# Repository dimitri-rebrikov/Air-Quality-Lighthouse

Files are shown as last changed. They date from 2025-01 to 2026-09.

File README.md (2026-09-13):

# Air-Quality-Lighthouse
Implementation of an indoor air quality monitor based on [ESPhome](https://esphome.io/) and built inside of a lighthouse model.

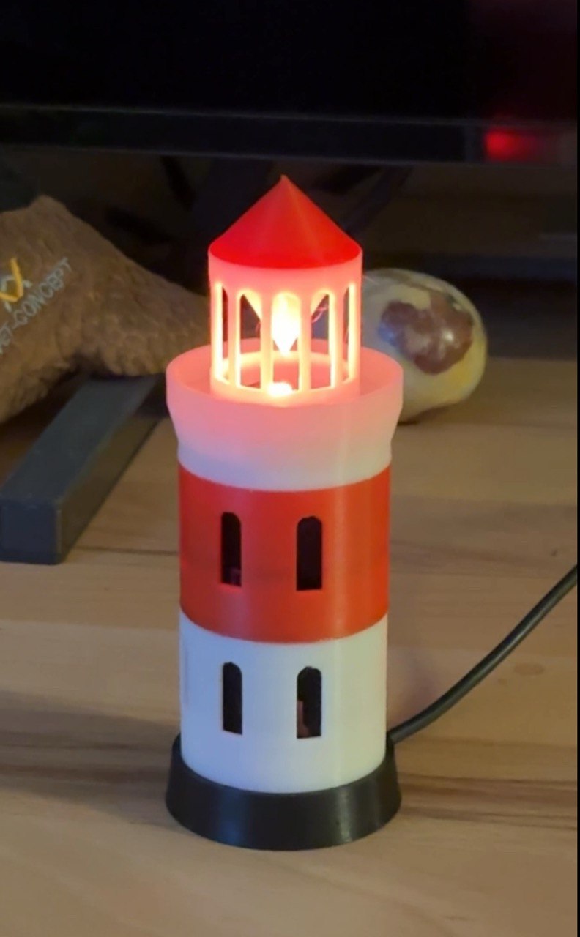
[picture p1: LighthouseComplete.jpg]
Lighthouse Complete


## Summary

The idea came from https://www.thingiverse.com/thing:5652921 where the ESP module's heat creates a chimney effect inside of the lighthouse model ensuring the air quality sensor always gets the air from outside of the housing.

This project provides the similar functionality: 
- visualizing of the air quality over the RGB LED light in the traffic light manner: from green over yellow to the flashing red 
- sending of the detailed air and environmental information to the home automation server

Instead of the direct coding in C/C++ it uses the ESPhome environment and "just sticks" the parts already implemented there together.

The lighthouse model is designed in OpenSCAD and is parametrizable so that it possible to use different ESP, Air Sensor and LED modules.

### Gallery

| | | |
| --- | --- | --- |
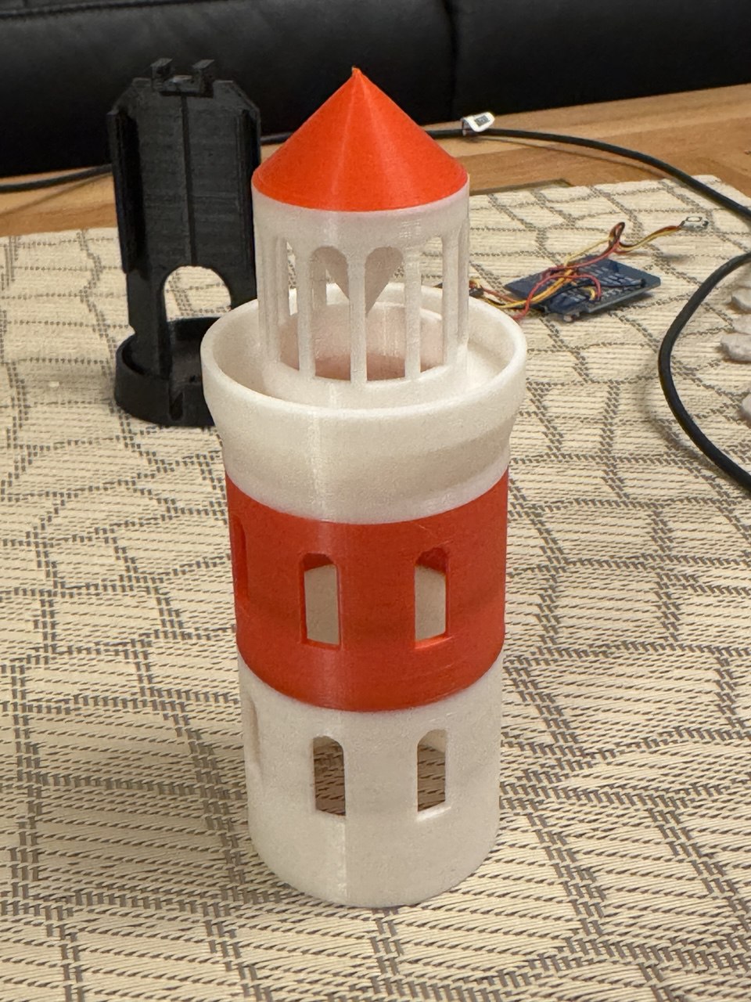
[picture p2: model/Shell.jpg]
Shell
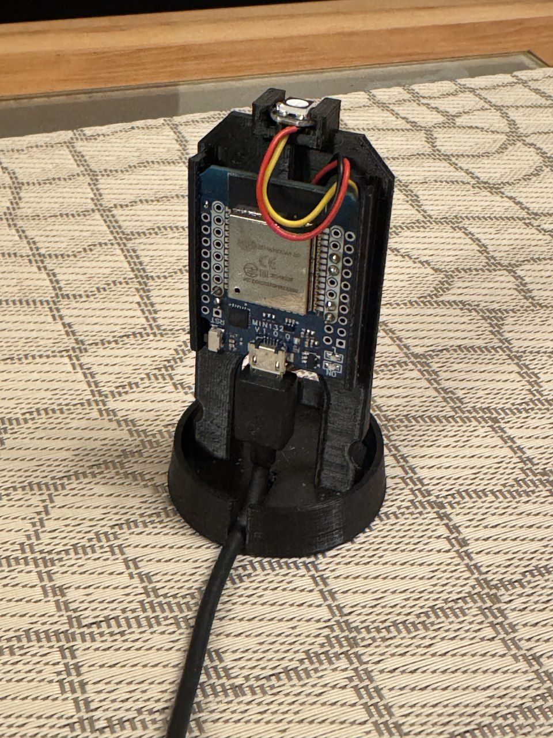
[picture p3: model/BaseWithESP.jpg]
BaseWithESP
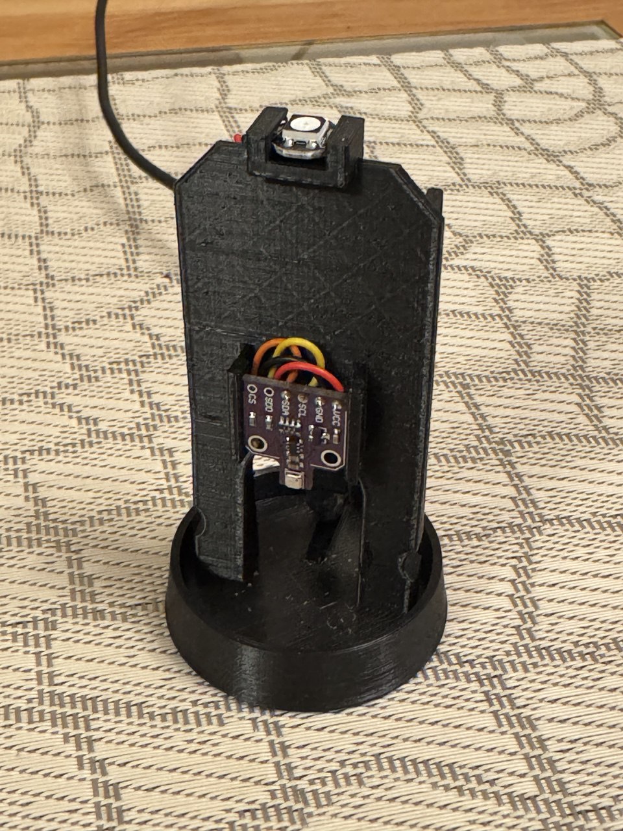
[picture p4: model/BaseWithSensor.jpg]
BaseWithSensor
|  |  |  | 

## Circuit
 
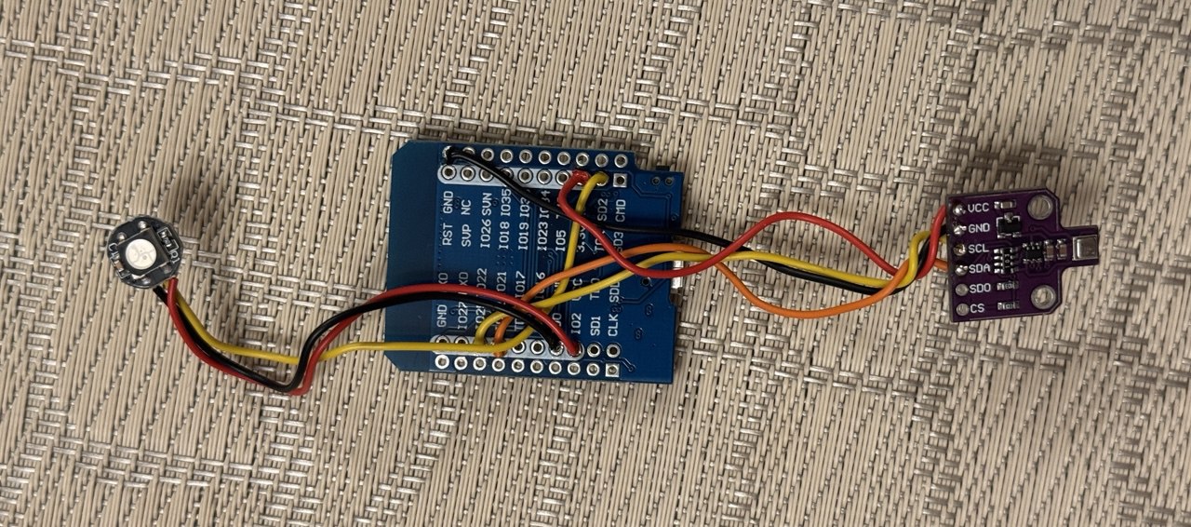
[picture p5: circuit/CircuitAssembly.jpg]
Circuit Assembly


Parts:
- ESP32 D1 Mini
- BME680 Sensor
- WS2812b RGB LED

## Model

The model is designed using OpenSCAD.
The [source file](model/Lighthouse.scad) contains multiple commented configuration parameters, so it is possible to change the design according to your needs.

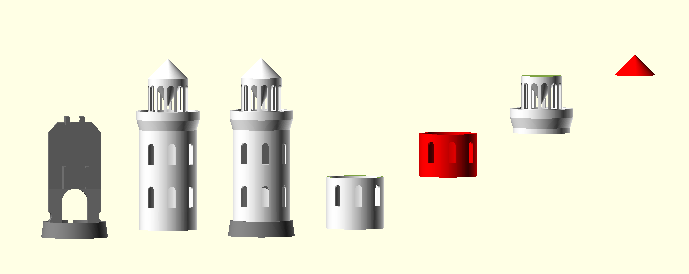
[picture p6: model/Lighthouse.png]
Lighthouse all parts


Parts:
- Base with the wall carrying the electronic boards
- Shell (walls, windows, lantern, roof)

The lantern is designed as an up side down cone with the idea to reflect the light from the LED under it spreading it in all directions.

The holders for ESP and Sensor are implemented as click in place.

The holder for the LED is implemented as a slide in place.

The big hole in the wall is for the wiring between the sensor and the ESP but also for the chimney effect.

The wall divides the inside of the lighthouse in 2 rooms: the air sensor room and the ESP room.
Only the sensor room has windows. So the chimney effect from the ESP soughs the air from the sensor room over the "chimney" hole which results the soughing of the outside air over the windows into the sensor room.

There is a lock mechanism between the base and the shell consists of the circular tongue on the inner wall of the shell and the grooves on the vertical wall of the base. The tongue has 2 symmetrical interruptions so the base can slide into the shell. Then the lock is activated by twisting the shell so the tongue come inside of the groove.

## 3D Printing

The corresponding STL files are in the `model` subdirectory.

The shell can be printed as one piece or as 4 pieces (ground/firs/second floor and the roof) for the different colorization.

For the printing of the piece with the lantern you will need to activate support.
Here is my config for the Ultimaker Cura:

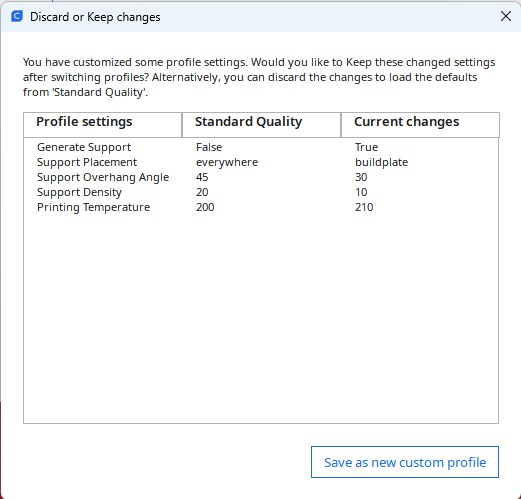
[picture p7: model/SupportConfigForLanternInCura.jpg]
SupportConfigForLanternInCura


## Code

The code is an [ESPhome](https://esphome.io/) configuration defined in an [yaml file](code/esphome.yaml).

You can open the [yaml file](code/esphome.yaml) in any editor and analyze what is doing by searching for the keywords on the [ESPhome website](https://esphome.io/).

### Compiling and installing the code

- install ESPhome environment as described in the [installation manual](https://esphome.io/guides/installing_esphome.html), or use [uv](https://docs.astral.sh/uv/) which needs no installation at all
- rename the [secrets.yaml_emplate](code/secrets.yaml_template) into `secrets.yaml` and fill the values
- connect the ESP to the PC using the USB cable
- open the command line window in the `code` subdirectory
- execute `uvx esphome -s esphome_name <your-name-for-the-device> run .\esphome.yaml` (or `esphome` instead of `uvx esphome` if you installed it)
- run the command in a **PowerShell or cmd** window (the one in VS Code is fine); if you prefer Git Bash, see [Shell notes](#shell-notes)
- the first build downloads the ESP32 toolchain (~1-2 GB) once; later builds are fast
- the esphome tool will compile and upload the code to the ESP
- the esphome will not exit but rather executes the code on the ESP and spool its log output 
- analyze the log output for possible issue
- after that it is safe do disconnect the ESP from the PC and power it from a USB power supply
- the code is now on the ESP and will be automatically started every time you power the ESP

#### Shell notes

Use **PowerShell or cmd** (also the one in VS Code). In Git Bash (MSys) the ESP32 toolchain aborts with
`ERROR: MSys/Mingw is not supported`, because of the `MSYSTEM` variable - Git Bash re-injects it into every
child process, so `env -u MSYSTEM` cannot help. Deleting it natively is inherited by everything below, so:

```bash
powershell -c 'del env:MSYSTEM; uvx esphome -s esphome_name <your-name-for-the-device> run esphome.yaml'
```

Add `-nop` after `powershell` if your PowerShell profile interferes. ESP8266 configs are unaffected.

### Temperature offset

That chimney effect does not keep the sensor on ambient air in practice: the reading stays about **3 °C too
high** (placing the ESP32 higher than the sensor did not change it), so the residual is compensated in
[esphome.yaml](code/esphome.yaml) with:

```yaml
bme68x_bsec2_i2c:
  temperature_offset: 3
```

- BSEC **subtracts** the value: `T_out = T_raw - f(heating, supply voltage) - temperature_offset`.
  So `3` reports 3 °C less; a negative value reports more.
- It also corrects the heat compensated relative humidity (a plain sensor filter would not).
- It is compiled into the firmware - changing it needs a recompile and flash. Check `supply_voltage` first,
  no offset can fix a wrong value there.

To find the value: run the device beside a reference thermometer (LED in its normal state, settled) and
compare averages, not single samples.

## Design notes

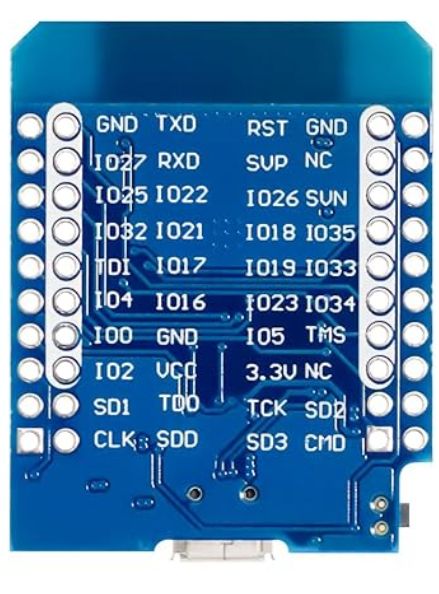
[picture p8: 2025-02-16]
circuit/ESP32D1MiniBackSide.jpg

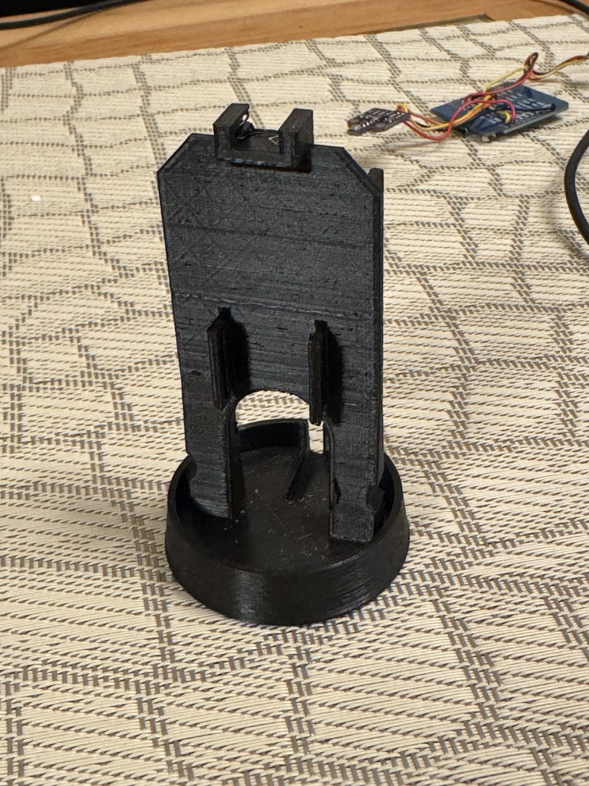
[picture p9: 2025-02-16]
model/BaseSensorSide.jpg

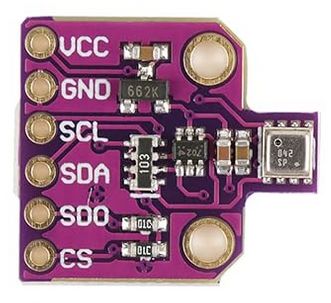
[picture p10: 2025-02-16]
circuit/BME680Sensor.jpg

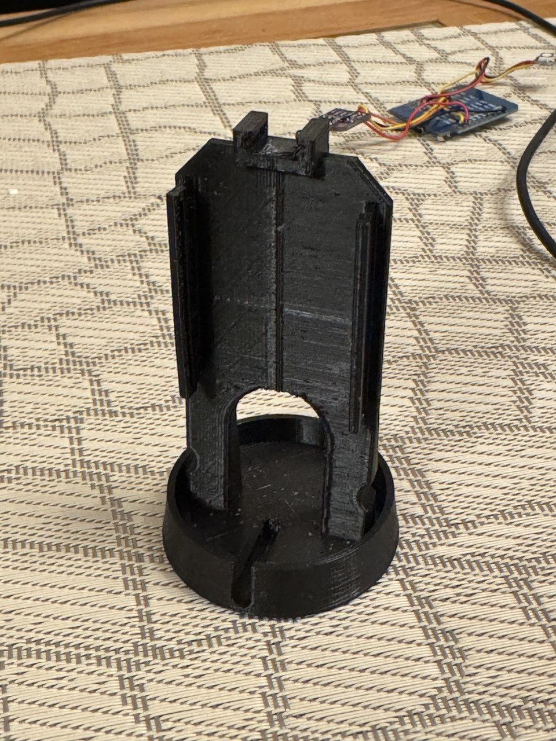
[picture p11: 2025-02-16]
model/BaseESPSide.jpg

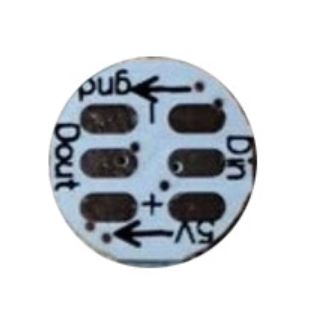
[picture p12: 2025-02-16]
circuit/WS2812bLedBackSide.jpg

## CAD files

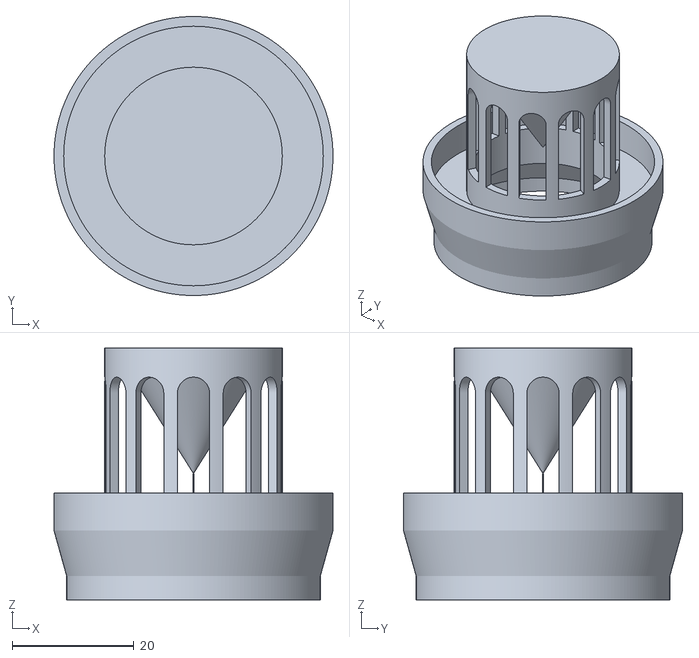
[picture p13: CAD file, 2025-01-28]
model/SecondFloor.stl
45.8 x 45.8 x 41.3

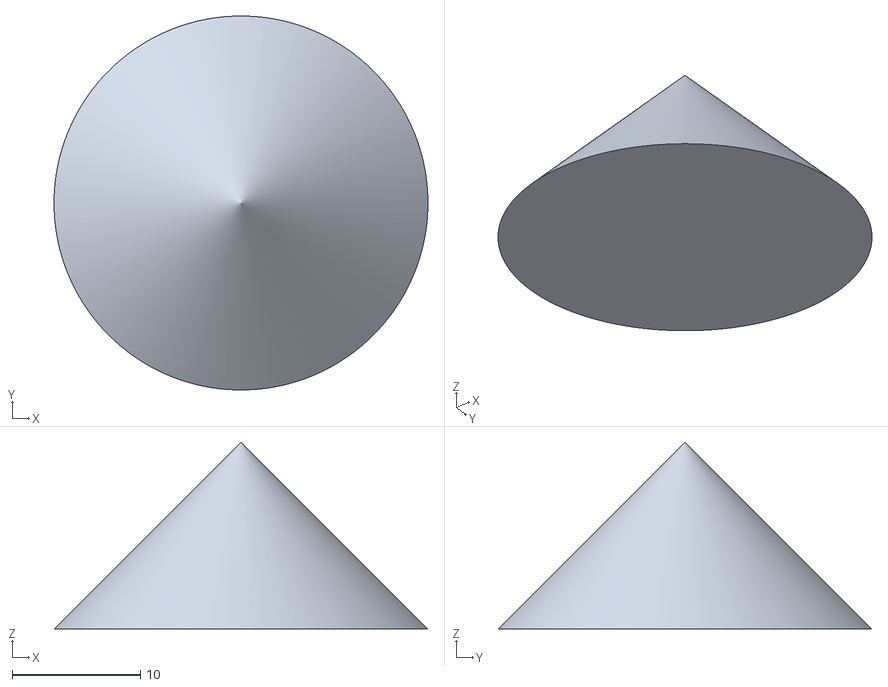
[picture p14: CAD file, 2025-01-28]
model/Roof.stl
29.2 x 29.2 x 14.6

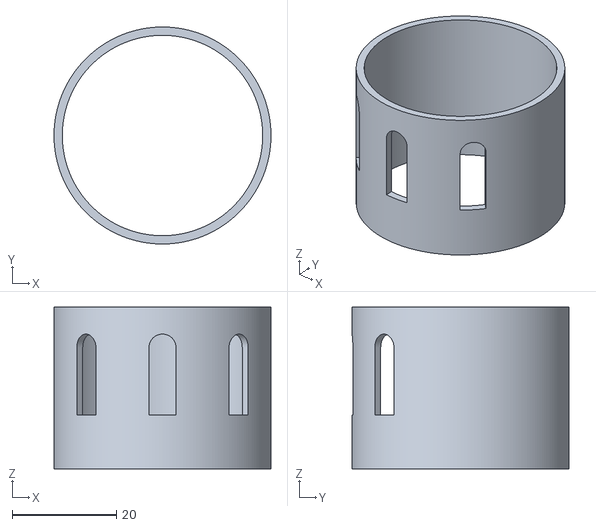
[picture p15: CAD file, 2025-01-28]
model/FirstFloor.stl
41.7 x 41.7 x 31.1

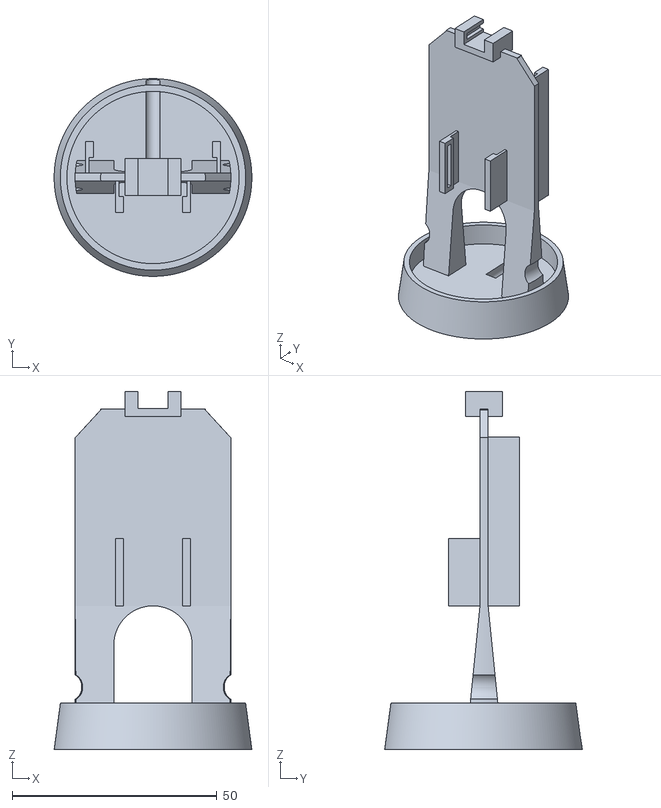
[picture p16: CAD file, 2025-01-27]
model/Base.stl
48.3 x 48.3 x 87.5

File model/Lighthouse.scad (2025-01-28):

cth=2; // wall thickens carrier

// esp card dimensions
esph=38.5; // height
espw=31; // width
espt=1.5; // thickness

// sensor card dimensions
senh=13.7;
senw=16.3;
sent=1.5;

// led card dimensions
ledw=9.4;
ledh=6.2;
ledt=1.9;

// generic holder
holdg=0.8; // groove to hold the card
holdwt=0.8; // wall thickness
holdbt=cth; // base thickness
holdxa=1.2; // extra thick wall area around groove
holdclr=0.2; // clearance between card and holder
holddi=5; // card distance to holder base
function holdh(cardh,hclr=holdclr,hxa=holdxa) = cardh+(hclr+hxa)*2;
function holdw(cardw,hclr=holdclr,hwt=holdwt) = cardw+(hclr+hwt)*2;
function holdd(cardt,hbt=holdbt,hdi=holddi,hxa=holdxa) = hbt+hdi+cardt+hxa;

// circuits carrier dimensions
cledholdd=holdd(ledt,hdi=1)-(ledt+2*holdxa); // how deep the led holder is integrated into carrier
cledh=cledholdd+5; // carrier height reserved for led
cesph=holdh(esph); // carrier height reserved for esp
cvwh=30; // carrier height reserver for the usb plug
cespw=sqrt(holdd(espt)^2+(holdw(espw)/2)^2)*2; // carrier width reserved for esp
ch=cledh+cesph+cvwh; // carrier height
cw=cespw; // carrier width
clh=ch-cledh; // carrier led area start height
cfth=cth*4; // carrier foot thickness

// lighthouse proportions
prbah=0.05; // base height
prf0h=0.30; // ground floor height
prf1h=0.30; // first floor height
prf2h=0.35; // second floor ( light and roof ) height
anr=45; // roof angle
prbw=1.1; // balcony diameter
prlw=0.7; // light diameter
prbrh=0.05; // balcony railing height
prbth=0.05; // balcony transition height

// technical
clr=0.2; // clearance between objects
th=1.6; // wall thickness

//lighthouse
di=cw+clr; // lighthouse inner diameter
ri=di/2; // lighthouse inner radius
ro=ri+th; // lighthouse outer radius
rol=ro*prlw; // light outer radius
rh=tan(anr)*rol; // roof height
ta=clh/(prbah+prf0h+prf1h)+rh; // lighthouse height
rob=ro*prbw; // balcony outer radius
rib=rob-th; // balcony inner radius
ril=rol-th; // light inner radius
tab=ch+th; // balcony height
tabr=tab+ta*prbrh; // balcony railing height
tar=ta-rh; // roof floor height
thr=th/sin(90-anr); // roof thickness

clw=(ril-clr)*2; // carrier led area narrow width

// base
rbi=ro+clr; // base inner radius
bta=ta*prbah; // base height
rbo=rbi+ro*0.15; // base outer radius

// cable channel
cabd=3.5; // cable diameter for cable channel

// light
lwic=12; // light windows number
lwico=0.7; // coefficient light window width to windows distance
lwiw=sin(360/lwic/2)*rol*2*lwico; // light windows width
lwih=(tar-tabr)*0.8; // light windows height

//floors
floh=ta*0.25; // floor height
h0h=bta; // ground floor height
h1h=h0h+floh; // first floor height
h2h=h1h+floh; // second floor height
hwiw=ro/4; // house windows width
hwih=floh/2; // house windows height
hwifh=(floh-hwih)/3*2; // house windows height over floor
lrih=lwih/3*2; // light reflector height
lrita=tabr+lwih/2-lrih/2; // light reflector position

lr=th*2; // lock radius
loa=asin(cfth / (2*ri)) * 2 + 20; // lock outcut angle

odist=rbo*2+20; // object distance

module cardHolder(cardw,cardh,cardt,hwt=holdwt,hxa=holdxa,hbt=holdbt,hdi=holddi,hclr=holdclr,slide=false) {
    h=holdh(cardh,hclr,hxa);
    w=holdw(cardw,hclr,hwt);
    d=holdd(cardt,hbt,hdi,hxa);
    translate([-w/2,0,0])
    difference() {
        // base quader
        linear_extrude (d) 
            square([w, h]);
        // outcut for thick the groove area
        translate([hwt+hxa,0,hbt])
            linear_extrude(d)
                square([w-(hwt+hxa)*2, h]);
        // esp outcut
        if(!slide) {
            translate([hwt,(h-cardh)/2,hdi+hbt])
                linear_extrude(cardt) 
                    square([cardw,cardh]);
        } else {
            translate([hwt,(h-cardh)/2,hdi+hbt])
                linear_extrude(cardt) 
                    square([cardw,cardh+hxa+1]);
        }
        // outcut for the thin wall area
        translate([hwt,0,hbt])
            linear_extrude(hdi-hxa)
                square([w-hwt*2, h]);
    };  
}

module espHolder() {
    cardHolder(espw,esph,espt);
}

module senHolder() {
    cardHolder(senw,senh,sent);
}

module ledHolder() {
    cardHolder(ledw,ledh,ledt,hdi=1,hwt=2,slide=true);
}

module carrierOutline() {
    polygon(points=[
        [0,0],[cw/2,0],[cw/2,clh],[clw/2,ch],[0,ch]
    ]);
}

module lockOutline(){
    difference(){
        circle(lr, $fn=200);
        translate([0,-lr,0]) square([lr, lr*2]);
    };
}

module lock() {
    union() {
        rotate([0,0,90+loa/2])
            rotate_extrude(angle=180-loa, $fn=200)
                translate([ro, h0h+hwifh-lr*2, 0])  
                    lockOutline();
        rotate([0,0,-(90-loa/2)])
            rotate_extrude(angle=180-loa, $fn=200)
                translate([ro, h0h+hwifh-lr*2, 0])  
                    lockOutline();
    }
}

module bodyOutline() {
    polygon(points=[
        [ri,0],[ro,0],
        [ro,tab-ta*0.06],
        [rob,tab],[rob,tabr],[rib,tabr], 
        [rib,tab],[rol,tab],
        [rol,tar],[0,ta],
        [0,tar-th],[ril, tar-th],
        [ril,tab-th],[ri, clh]
    ]); 
}

module lightReflectorOutline() {
    polygon(points=[
        [0,tar],[0,lrita],[ril,tar]
    ]);
}   

// carrier is the vertical wall
// with circuit holders
module carrier() {
    difference() {
        translate([0,thr/2,0])
        rotate([90,0,0])
        union(){
            linear_extrude(cth)
                union() {
                    carrierOutline();
                    mirror([1,0,0])
                        carrierOutline();
                };
            carrierFoot();
            translate([0,cvwh,cth])
                rotate([0,180,0]) 
                    espHolder();
            translate([0,cvwh,0])
                senHolder();
            translate([0,ch-cledholdd,(holdh(ledh)+cth)/2])
                rotate([-90,0,0]) 
                    ledHolder();
        };
        translate([0,cfth/2+1,0]) 
            window(cfth+2,cw/2,cvwh);
        // clearance for the edges
        translate([clr,0,clr]) bodyComplete(); 
        translate([clr,0,-clr]) bodyComplete(); 
        translate([-clr,0,clr]) bodyComplete();  
        translate([-clr,0,-clr]) bodyComplete();  
    }
}

// because of the big hole in the carrier
// it has a thick foot for more sturdiness
module carrierFoot() {
    translate([-cw/2,0,cth/2])
    rotate([0,90,0])
    linear_extrude(cw)
    polygon(points=[
        [-cfth/2,0],[cfth/2,0],[cth/2,cvwh],[-cth/2,cvwh]
    ]);
}
 
module bodyOnly() {
    rotate_extrude($fn=200)
        bodyOutline();
}

module lightReflector() {
    rotate_extrude($fn=200)
        lightReflectorOutline();
}

module baseOutline() {
    polygon(points=[
     [0,0],[rbi,0],[rbi,bta],[rbi+th,bta],[rbo,-th-cabd],[0,-th-cabd]
    ]);
}

// base is the round puck
// on wich the carier is mounted
module base() {
    rotate_extrude($fn=200)
        baseOutline();
}

module cableChannel() {
    translate([0,thr*1.5,bta])
    mirror([0,1,0])
    mirror([0,0,1])
    window(rbo,3.5,bta+cabd);
}

// base and carrier
module baseComplete() {
    color("gray")
    union() {
        difference() {
            base();
            cableChannel();
        };            
        carrier();
    }
}

module windowOutline(w,h) {
    union() {
        square([w,h-w/2]);
        translate([w/2,h-w/2]) circle(w/2, $fn=200);
    };
}  

// generich window
module window(r,w,h) {
    translate([0,-r,h/2])
    rotate([90,0,0])
    translate([-w/2,-h/2,-r])
    linear_extrude(height=r)
    windowOutline(w,h);
}

module lwindows() {
    for(ang = [0:360/lwic:360]) {
        rotate([0,0,ang]) window(rol,lwiw,lwih);
    }
}

module h0windows() {
    for(ang = [-45,0,45]) {
        rotate([0,0,ang]) window(ro,hwiw,hwih);
    }
}

module h1windows() {
    for(ang = [-45,0,45]) {
        rotate([0,0,ang]) window(ro,hwiw,hwih);
    }
}

// body is the outer shell of the lighthouse
module bodyComplete() {
    color("white")
    union() {
        difference() {
            bodyOnly();
            translate([0,0,tabr]) lwindows();
            translate([0,0,h0h+hwifh]) h0windows();
            translate([0,0,h1h+hwifh]) h1windows();
        };
        lightReflector();
        lock();
    }
}

// ground floor for separate print
module groundFloorSeparate() {
    difference() {
        bodyComplete();
        translate([-rob,-rob,h1h]) cube([rob*2,rob*2,ta]);
    };
}

// first floor for separate print
module firstFloorSeparate() { 
    difference() {
        bodyComplete();
        translate([-rob,-rob,0]) cube([rob*2,rob*2,h1h]);
        translate([-rob,-rob,h2h]) 
            cube([rob*2,rob*2,ta]);
    };
}

// second floor for separate print
module secondFloorSeparate() {
    difference() {
        bodyComplete();
        translate([-rob,-rob,0]) cube([rob*2,rob*2,h2h]);
        translate([-rob,-rob,tar]) cube([rob*2,rob*2,ta]);
    };
}
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

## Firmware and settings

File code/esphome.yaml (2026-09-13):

esphome:
  name: $esphome_name

esp32:
  board: wemos_d1_mini32

# Enable logging
logger:
  # level: VERY_VERBOSE

wifi:
  ssid: !secret wifi_ssid
  password: !secret wifi_password
  # Enable fallback hotspot (captive portal) in case wifi connection fails
  ap:
    password: !secret ota_password

captive_portal:

api:
  encryption:
    key: !secret esphome_api_key

ota:
  - platform: esphome
    password: !secret ota_password
    
mqtt:
  broker: !secret mqtt_broker
  username: !secret mqtt_username
  password: !secret mqtt_password
  discovery: True
  discover_ip: True 

light:
  - platform: esp32_rmt_led_strip
    id: led
    chipset: WS2812
    channel_colors: GRB
    pin: GPIO13
    num_leds: 1
    restore_mode: ALWAYS_ON
    effects:
      - pulse:
          name: "Stabilizing"
          transition_length: 0.25s
          update_interval: 0.5s
          min_brightness: 50%
          max_brightness: 70%
      - pulse:
          name: "Uncertain"
          transition_length: 0.5s
          update_interval: 1s
          min_brightness: 50%
          max_brightness: 70%
      - pulse:
          name: "Calibrating"
          transition_length: 1s
          update_interval: 2s
          min_brightness: 50%
          max_brightness: 70%
      - pulse:
          name: "Warning1"
          transition_length: 0s
          update_interval: 1s
          min_brightness: 0%
          max_brightness: 70%
      - pulse:
          name: "Warning2"
          transition_length: 0s
          update_interval: 0.5s
          min_brightness: 0%
          max_brightness: 70%
      - pulse:
          name: "Warning3"
          transition_length: 0s
          update_interval: 0.25s
          min_brightness: 0%
          max_brightness: 70%

i2c:

bme68x_bsec2_i2c:
  address: 0x77
  model: bme680
  operating_age: 28d
  sample_rate: LP
  supply_voltage: 3.3V
  # The BME680 sits in the sensor room, where the chimney effect does not keep the
  # air on ambient level in practice, so the reading stays about 3 °C too high
  # (moving the ESP32 above the sensor did not change it). BSEC SUBTRACTS this
  # value from the reading, see
  #   T_out = T_raw - f(heating, supply voltage) - temperature_offset
  # so 3 means "report 3 °C less" and a negative value would report more.
  # The same value is applied to the heat compensated relative humidity.
  # It is compiled into the firmware: changing it needs a recompile + flash.
  temperature_offset: 3

sensor:
  - platform: bme68x_bsec2
    temperature:
      name: "BME680 Temperature"
    pressure:
      name: "BME680 Pressure"
    humidity:
      name: "BME680 Humidity"
    iaq:
      name: "BME680 IAQ"
      id: iaq
    co2_equivalent:
      name: "BME680 CO2 Equivalent"
    breath_voc_equivalent:
      name: "BME680 Breath VOC Equivalent"

text_sensor:
  - platform: bme68x_bsec2
    iaq_accuracy:
      name: "BME680 IAQ Accuracy"
      id: iaqa

  - platform: template
    name: "BME680 IAQ Classification"
    icon: "mdi:checkbox-marked-circle-outline"
    lambda: |-
      auto l = id(led).turn_on().set_brightness(0.7).set_effect("None");
      auto aiq = "";
      int iaq_state = int(id(iaq).state);
      std::string iaqa_state = id(iaqa).state;
      if (iaq_state <= 50) {
        aiq = "Excellent";
        l.set_rgb(0.0, 1.0, 0.0);
      }
      else if (iaq_state >= 51 && iaq_state <= 100) {
        aiq = "Good";
        l.set_rgb(0.5, 1.0, 0.0);
      }
      else if (iaq_state >= 101 && iaq_state <= 150) {
        aiq = "Lightly polluted";
        l.set_rgb(1.0, 1.0, 0.0);
      }
      else if (iaq_state >= 151 && iaq_state <= 200) {
        aiq = "Moderately polluted";
        l.set_rgb(1.0, 0.5, 0.0);
      }
      else if (iaq_state >= 201 && iaq_state <= 250) {
        aiq = "Heavily polluted";
        l.set_rgb(1.0, 0.0, 0.0);
        l.set_effect("Warning1");
      }
      else if (iaq_state >= 251 && iaq_state <= 350) {
        aiq = "Severely polluted";
        l.set_rgb(1.0, 0.0, 0.0);
        l.set_effect("Warning2");
      }
      else if (iaq_state >= 351) {
        aiq =  "Extremely polluted";
        l.set_rgb(1.0, 0.0, 0.0);
        l.set_effect("Warning3");
      }
      else {
        aiq = "error";
        l.set_rgb(1.0, 1.0, 1.0);
        l.set_effect("Warning3");
      }
      // overwrite the light effect if the sensor is not yet calibrated
      if ( iaqa_state != "Calibrated") {
        if(iaqa_state.empty()) {
          // just show white light until the IAQ accuracy is unknown
          l.set_rgb(1.0, 1.0, 1.0);
          l.set_effect("None");
        } else {
          // use the state as the name of the light effect
          l.set_effect(id(iaqa).state);
        }
      }
      l.perform();
      return {aiq};

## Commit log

2025-01-05 added some info to readme and provided first scetch of the lighthouse model
    [Lighthouse.scad]
2025-01-05 added windows and base
    [Lighthouse.scad]
2025-01-05 added house windows
    [Lighthouse.scad]
2025-01-09 defined light reflector and stared with electronic carrier
    [Lighthouse.scad]
2025-01-11 created carrier, sliced floors for multiple color printing
    [Lighthouse.scad]
2025-01-11 refactored to base everything on the electronics size
    [Lighthouse.scad]
2025-01-11 implemented: 1) lock between body and base; 2) foot for the carrier
    [Lighthouse.scad]
2025-01-11 fixed color name
    [Lighthouse.scad]
2025-01-12 implemented cable channel
    [Lighthouse.scad]
2025-01-15 exported Base as STL file to print
    [Base.stl]
2025-01-15 fixed outcut for the lock slide in
    [Lighthouse.scad]
2025-01-15 created STL file for the Ground Floor
2025-01-21 switched to ESP32 mini
2025-01-26 introduced holders for all circuit cards
    [Base.stl, Lighthouse.scad]
2025-01-27 new version of ground floor because of changed base design
2025-01-27 reserved place for usb plug; redesigned led holder; misc
    [Base.stl, Lighthouse.scad]
2025-01-28 added separated first floor
    [FirstFloor.stl]
2025-01-28 added separated roof
    [Roof.stl]
2025-01-28 added separated second floor and the whole building
    [Lighthouse.scad, SecondFloor.stl]
2025-01-29 introduced led blink effects for the different air quality states
2025-02-11 refactored the led effects
2025-02-16 documented circuit and model; refactored files/directory structure
    [Base.stl, FirstFloor.stl, Lighthouse.scad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]
2026-09-13 provided temperature offset for the enclosure compensation
